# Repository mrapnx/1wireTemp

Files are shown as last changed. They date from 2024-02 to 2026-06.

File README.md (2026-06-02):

1-Wire Busmaster, der die Temperaturen (und Füllstände) angeschlossener 1-Wire Sensoren abfragt und auf einem Display anzeigt sowie per WiFi an einen MQTT Host überträgt.
Durch geringen Stromverbrauch ideal fürs Wohnmobil geeignet.

<kbd>grafik</kbd>
<kbd></kbd>
<kbd></kbd>

# Hardware
## Busmaster mit Display
+ Arduino Nano 33 IoT
+ Display Joy-IT SBC-LCD02 (ILI9163C 1.44" TFT 128x128)
+ Sensor-Button
+ Streifenplatine
+ Gehäuse (Bedieneinheit Gehäuse-Basis.stl / Bedieneinheit Gehäuse-Front.stl)
+ Optional: Temperatursensor DS18B20

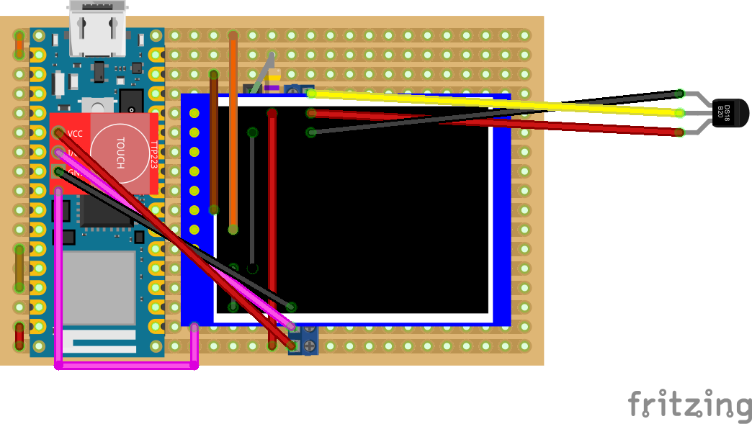
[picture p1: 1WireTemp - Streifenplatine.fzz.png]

  
## Adapter für Tanksonde
+ [Votronic Tanksonde 12-24k](https://www.votronic.de/tankgeber/tankelektrode-14-24-k-und-15-50-k/)
+ Streifenplatine
+ 1-Wire DS2438 Sensor
+ RJ45 Buchse
+ 3 Port-Klemme
+ Gehäuse (DS2438 Sondenadapter Gehäuse-Unterteil.stl)
  
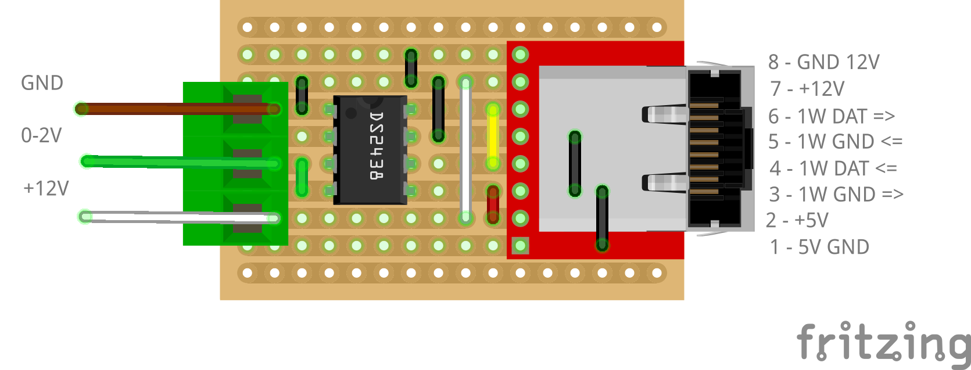
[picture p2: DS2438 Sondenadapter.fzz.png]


## 12V Injektor
+ 2x RJ 45 Buchsen
+ 2 Port-Klemme
+ Downstepper

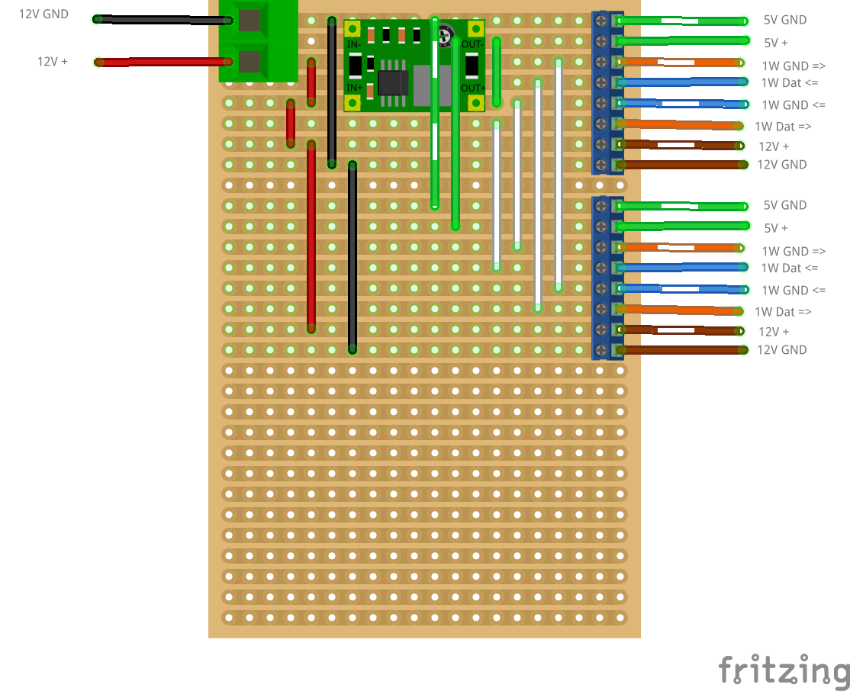
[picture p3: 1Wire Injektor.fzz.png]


# Software
+ VS Code
+ Plaftorm.IO
=> Einfach Repo in Platform.IO öffnen

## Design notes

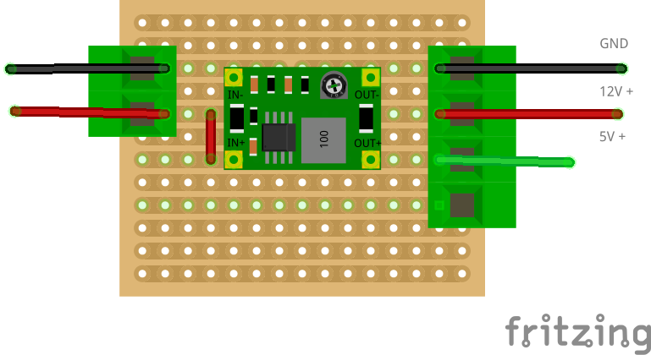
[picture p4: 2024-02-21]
1Wire Netzteil.fzz.png

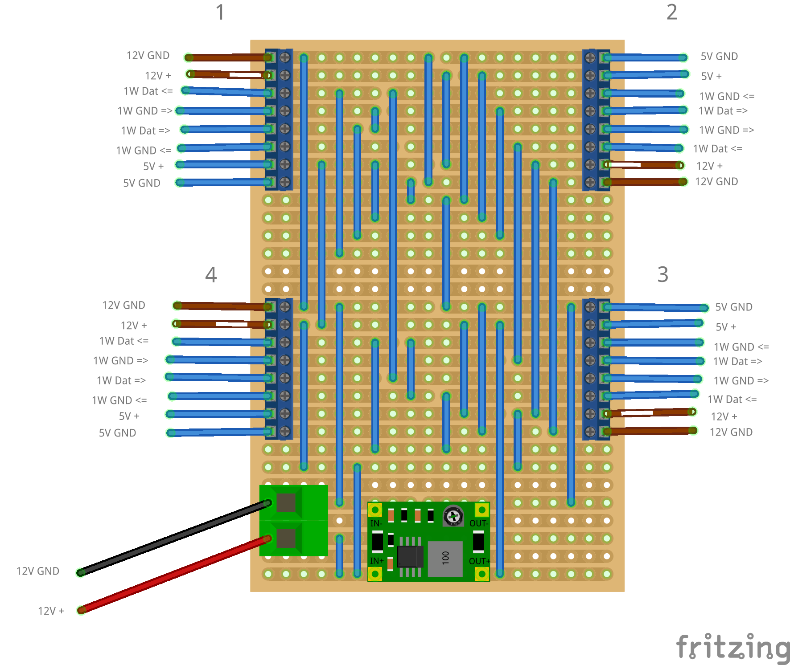
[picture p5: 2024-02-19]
1Wire Verteiler.fzz.png

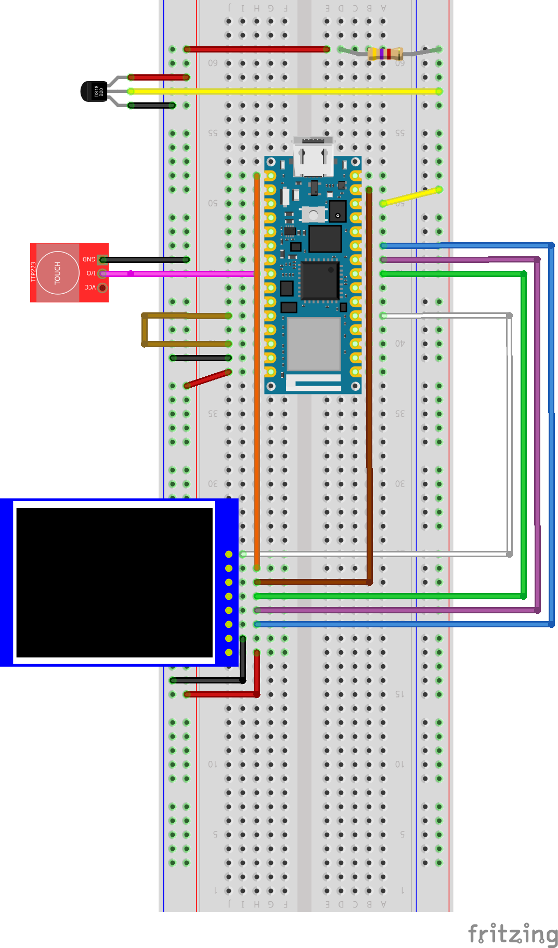
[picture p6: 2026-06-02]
1WireTemp.fzz.png

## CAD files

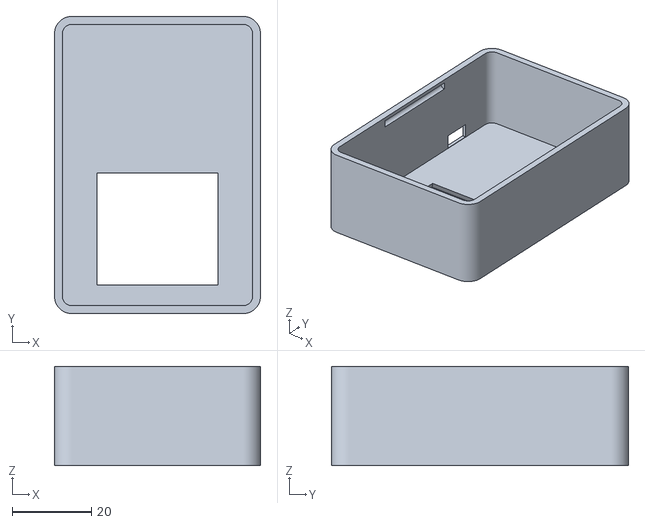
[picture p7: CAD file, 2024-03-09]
Bedieneinheit Gehäuse-Front.stl
52.0 x 75.0 x 25.0

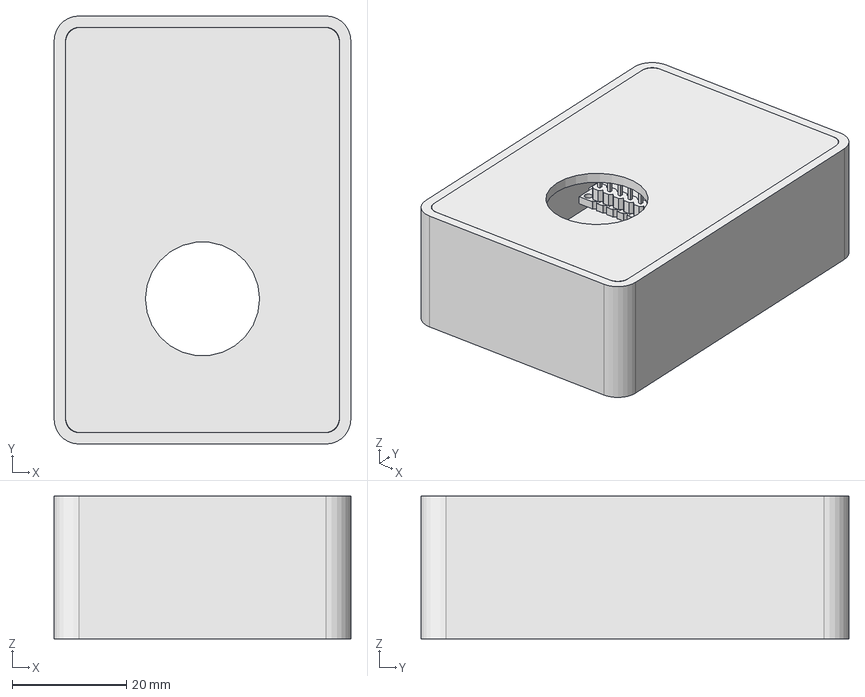
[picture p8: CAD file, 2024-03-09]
Bedieneinheit Gehäuse.FCStd
52.0 x 75.0 x 25.0 mm
Front
Nano_33IoT Body
User Library-arduino_nano_reset core
User Library-arduino_nano_reset shell
atmegaSAMD21
HSMG-C190 LED
HSMG-C190 LED001
ZX62-AB-5PA Micro USB
LSM6DS3 Accelerometer
MPM3610 Step-Down Module
NINA-W102 Body
NINA-W102 Antenna
NINA-W102 Cover
ATECC608A No Lead Crypto Auth
CL21A226MQCLQNC Capacitor
TDK C1005 Capacitor
TDK C1005 Capacitor001
CL21A226MQCLQNC Capacitor001
TDK C1005 Capacitor002
TDK C1005 Capacitor003
PRTR5V0U2X Protection Diode
PMEG6020AELR Diode
C0805C472KDRACTU Capacitor
TDK C1005 Capacitor004
BLM18PG471SN1D Ferrite Bead
TDK C1005 Capacitor005
TDK C1005 Capacitor006
TDK C1005 Capacitor007
GRM188R61E475KE11D Capacitor
RC0402FR-07100KL Resistor
RC0402FR-07100KL Resistor001
RC0402FR-07330RL Resistor
RC0402FR-07330RL Resistor001
RC0402FR-07330RL Resistor002
TDK C1005 Capacitor008
RC0402FR-074K7L Resistor
RC0402FR-074K7L Resistor001
GRM155R61E105KA12D Capacitor
TDK C1005 Capacitor009
RC0402FR-071KL Resistor
RC0402FR-07100KL Resistor002
RC0402FR-07100KL Resistor003
AC0402JR-0724KL Resistor
AC0402JR-0775KL Resistor
dd74adb0230a45f793cde4f0c868591f003
dd74adb0230a45f793cde4f0c868591f004
Basis

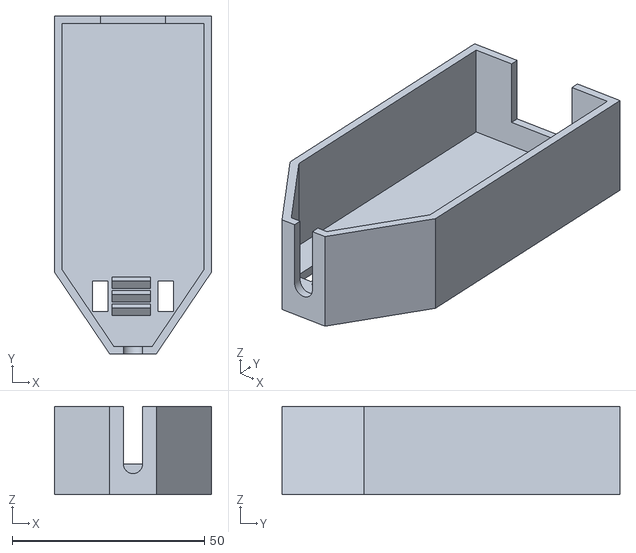
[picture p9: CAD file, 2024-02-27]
DS2438 Sondenadapter Gehäuse-Unterteil.stl
41.0 x 88.0 x 23.0

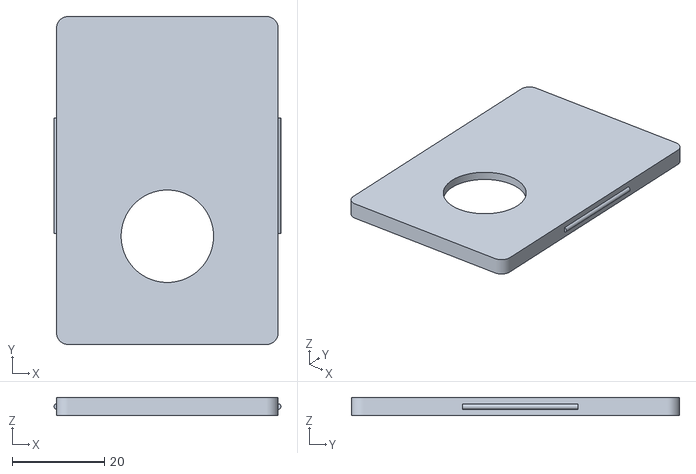
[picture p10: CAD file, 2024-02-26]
Bedieneinheit Gehäuse-Basis.stl
49.1 x 71.0 x 4.00

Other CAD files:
DS2438 Sondenadapter Gehäuse.FCStd

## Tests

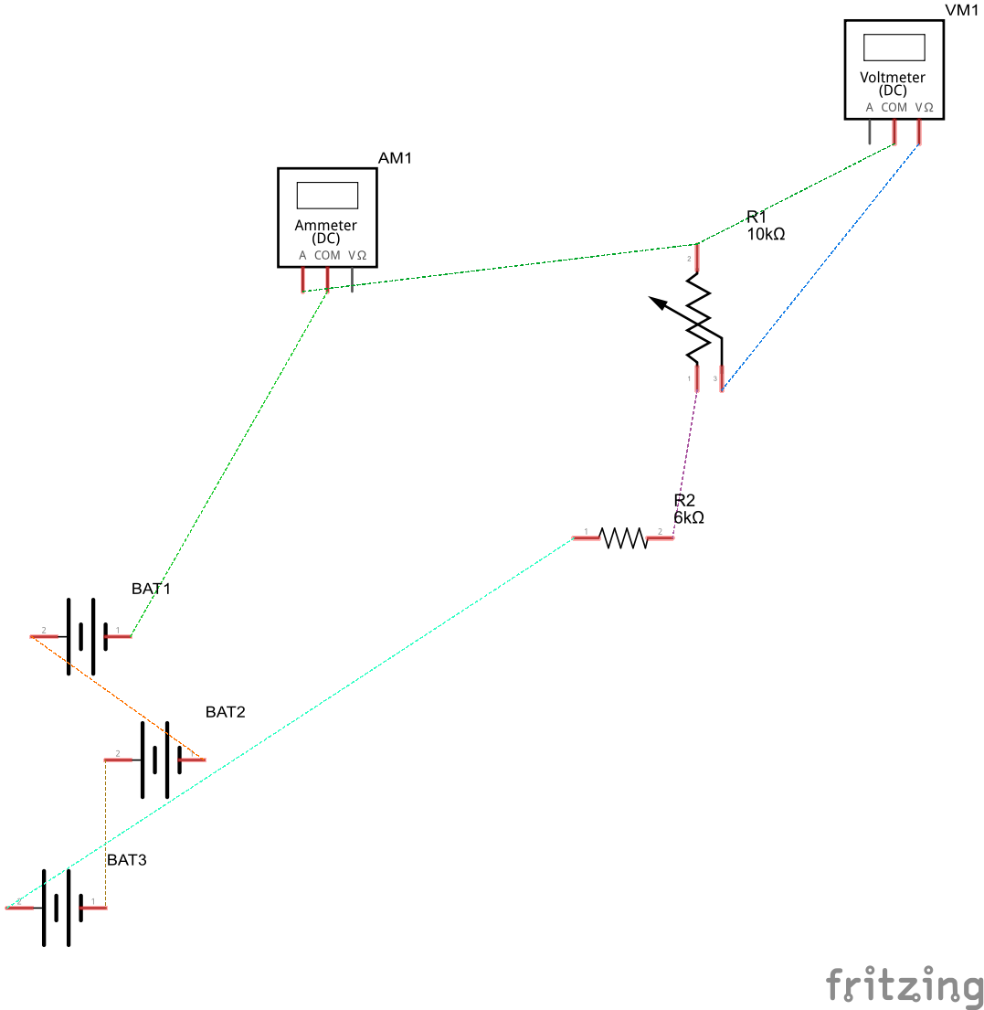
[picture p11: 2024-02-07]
Voltmeter Test_Schaltplan.png

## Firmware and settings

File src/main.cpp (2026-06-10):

/* *************   Wie es geht....

loadConfig()
1. Config wird aus Flash geladen 
   => Config liegt in config.sensorConfig vor

setup1Wire()
2. Alle Sensoren werden per oneWire.search() ermittelt  
   => Sensoren liegen in dallasSensors vor
3. Es wird durch alle Sensoren in dallasSensors iteriert und die Config-Werte ermittelt
4. Zusammen mit den Config-Werten wird nun per addSensor() ein Eintrag in sensors.sensorList erzeugt
   => Nun liegen alle Sensoren in sensors.sensorList vor

loop()
5. Per updateTemperatures() und updateLevels() werden anhand der Sensor-Adressen in sensors.sensorList die aktuellen Werte aus dallasSensors bzw. aus DS2438 ermittelt und in sensors.sensorList geschrieben
6. Per sensorValueToDisplay() wird nun der Wert mit Hilfe der Config im Sensor in einen C-String konvertiert

*/

#include <Arduino.h>
#include <avr/dtostrf.h>
#include <Wire.h>
#include <WiFiNINA.h>
#include <OneWire.h>
#include <DallasTemperature.h>
#include <PubSubClient.h>
#include <SPI.h>
#include <FlashStorage_SAMD.h>
#include <TFT_ILI9163C.h> // Achtung! In der TFT_IL9163C_settings.h muss >> #define __MRA_PCB__ << aktiv sein!. Offenbar ist mein Board nicht von dem Bug betroffen, von dem andere rote Boards betroffen sind. Siehe Readme der TFT_IL9163 Lib.
#include <DS2438.h>
#include "sensors.h"

//#define DRYRUN // Erzeugt Dummy-Sensoren, wenn keine echten angeschlossen sind

// *************** Konfig-Grundeinstellungen
const int sensorConfigCount = 10;  // Gibt fan, wie viele Sensoren konfiguriert und gespeichert werden können

typedef struct {
  char    head           [5] = "MRAb";
  // WLAN
  boolean wifiEnabled        = true;
  char    wifiMode           = 'a'; // a = Access Point / c = Client
  int     wifiTimeout        = 10;
  char    wifiSsid      [21] = "ArduinoAP";
  char    wifiPass      [21] = "ArduinoAP";

  // MQTT-Zugangsdaten
  boolean mqttEnabled        = false;
  char    mqttServer    [21] = "127.0.0.1"; // war: char *mqttServer
  int     mqttPort           = 1883;
  char    mqttName      [21] = "ArduinoClient";
  char    mqttUser      [21] = "ArudinoNano";
  char    mqttPassword  [21] = "DEIN_MQTT_PASSWORT";
  
  // Sensor-Konfiguration
  PersistantSensorConfig sensorConfig[sensorConfigCount];  

  char    foot           [5] = "MRAe";
} Config;

// WLAN-Port
const int wifiPort = 80; // Port, auf den der HTTP-Server lauscht

// Reset Pin
#define RST_PIN  21   // D21

// Button Pin
#define BUTTON_PIN 18 // D18

// Display
#define TFT_LED  2    // Rot    LED   D2 +3.3V
#define TFT_CLK  13   // Orange SCK   D13 / Nicht änderbar
#define TFT_MOSI 11   // Braun  SDA   D11 / Nicht änderbar
#define TFT_DC   5    // Grün   A0    D5
#define TFT_RST  6    // Lila   RES   D6
#define TFT_CS   7    // Blau   CS    D7
                      // Schw.  GND   GND
                      // Rot    VCC   +3.3V   

int       xBegin      = 0;
int       yBegin      = 33;
uint16_t  textColor   = 0xFFFF; // Weiß
uint16_t  backColor   = 0x0000; // Schwarz
boolean   initalClear = false;


// 1-Wire
const int PinOneWireBus = 10; // Pin, an dem der 1-Wire-Bus angeschlossen ist // = D10

// Intervalle
const int wifiCheckInterval   = 10;  // Frequenz in Sekunden, in der die WLAN-Verbindung versucht wird
const int tempCheckInterval   = 5;   // Frequenz in Sekunden, in der die Temperaturen abgefragt werden
const int levelCheckInterval  = 2;   // Frequenz in Sekunden, in der die Füllstände abgefragt werden
const int sendInterval        = 10;  // Frequenz in Sekunden, in der die Temperaturen an MQTT gesendet werden
const int displayInterval     = 10;  // Frequenz in Sekunden, in der die Temperaturen angezeigt werden
const int blinkInterval       = 500; // Frequenz in Millisekunden, in der die orange LED bei Fehlern blinkt


// ***************  Globale Variablen

// Allgemein
unsigned long tempCheckLast   = 0;
unsigned long levelCheckLast  = 0;
unsigned long sendLast        = 0;
unsigned long displayLast     = 0;
unsigned long wifiCheckLast   = 0;
unsigned long blinkLast       = 0;
boolean       blinking        = false;
boolean       buttonState     = false;
boolean       dummySensors    = false;

// 1-Wire
OneWire           oneWire(PinOneWireBus);     // 1-Wire Grundobjekt
DallasTemperature dallasSensors(&oneWire);    // 1-Wire Objekt für Temperatursensoren
Sensors           sensors;                    // Sensorliste

// Webserver
IPAddress   ip; 
WiFiServer  server(wifiPort);
WiFiClient  client; 
int         status = WL_IDLE_STATUS;

// MQTT-Client
WiFiClient   wifiClient;
PubSubClient mqttClient(wifiClient);

// Display
TFT_ILI9163C tft = TFT_ILI9163C(TFT_CS, TFT_DC, TFT_RST);

// Speicher
FlashStorage(configStorage, Config);
Config config;

// *************** Deklaration der Funktionen

// Hilfs-Funktionen
char* fillBlank(const char* input, const u_int length);

// Zustands-Funktionen
boolean sensorsFine();
boolean wifiFine();
boolean checkWiFi();
boolean connectToMQTT();

// Config-Funktionen
boolean loadConfig();
void saveConfig();
void printConfig(Config &pconfig);
void copyConfig(const Config &from, Config &to);

// Sensorlisten-Funktionen
void addSensor(const SensorAddress address, const SensorName name, const SensorType type, const SensorCategory category, const SensorValueFormat format, const SensorValueFormatMin formatMin, const SensorValueFormatMax formatMax, const SensorValuePrecision precision, const SensorValueMin min, const SensorValueMax max, float value); 
void addSensor(Sensor sensor);
void removeSensor(SensorAddress address);
boolean updateSensorValue(const SensorAddress address, const float value);
void clearSensorList();
boolean getSensorCategory(const SensorAddress address, SensorCategory& category);
boolean getSensorConfig(const SensorAddress address, SensorConfig &output);

// Ein- & Ausgabe-Funktionen
void updateTemperatures();
void updateLevels();
void printSensors();
void printSensorAddresses();
void printWiFiStatus();
void displayBackground(); 
void displayValues(); 
void sendTemperaturesToMQTT();
boolean getButtonState();
void reset();

// HTTP-Funktionen
char* getValue(const String& data, const char* key);
String getValuesAsHtml();
char* urlDecode(const char* input);
int hexToDec(char c);
void htmlGetHeader(int refresh);
void htmlGetStatus();
void htmlGetConfig();
void htmlSetConfig();
void httpProcessRequests();

//  Setup-Funktionen
void setup1Wire(); 
void setupDisplay();
void setupMemory();
void setupWifi();
void setup();

// ***************  Funktionen *********************
char* fillBlank(const char* input, const u_int length) {
  static char result[255];
  strcpy(result, input);
  while (strlen(result) < length) {
    strcat(result, " ");
  }
  return result;
  
}


char* urlDecode(const char* input) {
  // Decode URL-encoded data
  String decoded = "";
  char a, b;
  for (size_t i = 0; i < strlen(input); i++) {
    if (input[i] == '%') {
      a = input[++i];
      b = input[++i];
      decoded += char((hexToDec(a) << 4) | hexToDec(b));
    } else {
      if (input[i] == '+') {
        decoded += ' ';
      } else {
        decoded += input[i];
      }
    }
  }

  char* result = new char[decoded.length() + 1];
  strcpy(result, decoded.c_str());
  return result;
}

int hexToDec(char c) {
  return (c >= '0' && c <= '9') ? c - '0' : (c >= 'A' && c <= 'F') ? c - 'A' + 10 : (c >= 'a' && c <= 'f') ? c - 'a' + 10 : 0;
}

char* getValue(const String& data, const char* key) {
  static char result[100]; // Annahme: Der Wert passt in einen 100-Byte-Puffer
  String delimiter = "=";
  char temp[100];
  int keyIndex = data.indexOf(key + delimiter);
  int endIndex;

  Serial.print("getValue(");
  Serial.print(key);
  Serial.println(") begin");
  if (keyIndex == -1) {
    return nullptr;  // Wenn der Schlüssel nicht gefunden wurde, leeres C-String zurückgeben
  }

  keyIndex += strlen(key) + delimiter.length();

  endIndex = data.indexOf('&', keyIndex);
  if (endIndex == -1) {
    endIndex = data.length();
  }

  data.substring(keyIndex, endIndex).toCharArray(result, sizeof(result));

  // Füge den nullterminierenden Zeichen manuell hinzu
  result[sizeof(result) - 1] = '\0';
  Serial.print("  result vor urldecode: ");
  Serial.println(result);
  strcpy(temp, urlDecode(result));
  strcpy(result, temp);
  Serial.print("  result nach urldecode: ");
  Serial.println(result);
  Serial.println("getValue()");
  return result;
}

void copyConfig(const Config &from, Config &to) {
  Serial.println("copyConfig() begin");
  // WiFi
         to.wifiEnabled  = from.wifiEnabled;
         to.wifiMode     = from.wifiMode;
         to.wifiTimeout  = from.wifiTimeout;
  strcpy(to.wifiSsid,      from.wifiSsid);
  strcpy(to.wifiPass,      from.wifiPass);

  // MQTT
         to.mqttEnabled  = from.mqttEnabled;
  strcpy(to.mqttServer,    from.mqttServer);
  strcpy(to.mqttUser,      from.mqttUser);
         to.mqttPort     = from.mqttPort;
  strcpy(to.mqttName,      from.mqttName);
  strcpy(to.mqttPassword,  from.mqttPassword);
  
  // Sensor-Konfig
  for (int i = 0; i < sensorConfigCount; i++) {
    strcpy(to.sensorConfig[i].address,    from.sensorConfig[i].address);  
    strcpy(to.sensorConfig[i].config.name,       from.sensorConfig[i].config.name);  
    strcpy(to.sensorConfig[i].config.format,     from.sensorConfig[i].config.format);  
           to.sensorConfig[i].config.formatMin = from.sensorConfig[i].config.formatMin;
           to.sensorConfig[i].config.formatMax = from.sensorConfig[i].config.formatMax;
           to.sensorConfig[i].config.precision = from.sensorConfig[i].config.precision;
           to.sensorConfig[i].config.min       = from.sensorConfig[i].config.min;
           to.sensorConfig[i].config.max       = from.sensorConfig[i].config.max;
    strcpy(to.sensorConfig[i].config.interpolation, from.sensorConfig[i].config.interpolation);
  }
  Serial.println("copyConfig() end");
};

void printConfig(Config &pconfig) {
  Serial.println("printConfig() begin");

  Serial.print("  wifiEnabled: ");
  Serial.println(int(pconfig.wifiEnabled));

  Serial.print("  ssid: ");
  Serial.println(pconfig.wifiSsid);

  Serial.print("  pass: ");
  Serial.println(pconfig.wifiPass);

  Serial.print("  mode: ");
  Serial.println(pconfig.wifiMode);

  Serial.print("  wifiTimeout: ");
  Serial.println(pconfig.wifiTimeout);

  Serial.print("  mqttEnabled: ");
  Serial.println(int(pconfig.mqttEnabled));

  Serial.print("  mqttServer: ");
  Serial.println(pconfig.mqttServer);

  Serial.print("  mqttPort: ");
  Serial.println(pconfig.mqttPort);

  Serial.print("  mqttName: ");
  Serial.println(pconfig.mqttName);

  Serial.print("  mqttUser: ");
  Serial.println(pconfig.mqttUser);

  Serial.print("  mqttPassword: ");
  Serial.println(pconfig  .mqttPassword);

  for (int i = 0; i < sensorConfigCount; i++) {
    Serial.print("  sensorConfig");  
    Serial.print(i);  
    Serial.print(": Address: ");  
    Serial.print(pconfig.sensorConfig[i].address);  
    Serial.print(" Name: ");  
    Serial.print(pconfig.sensorConfig[i].config.name);  
    Serial.print(" Format: ");  
    Serial.print(pconfig.sensorConfig[i].config.format);  
    Serial.print(" Precision: ");  
    Serial.print(pconfig.sensorConfig[i].config.precision);  
    Serial.print(" Min: ");  
    Serial.print(pconfig.sensorConfig[i].config.min);  
    Serial.print(" Max: ");  
    Serial.print(pconfig.sensorConfig[i].config.max);  
    Serial.print(" Interpolation: ");  
    Serial.println(pconfig.sensorConfig[i].config.interpolation);  
  }

  Serial.println("printConfig() end");
}

void clearSensorList() {
  // Befreie den Speicher von sensorList
  free(sensors.sensorList);

  // Setze die Anzahl der Sensoren auf 0
  sensors.count = 0;

  // Setze den Zeiger auf null, um sicherzustellen, dass er nicht auf ungültigen Speicher zeigt
  sensors.sensorList = nullptr;
}

void saveConfig() {
  Serial.println("saveConfig() begin");

  Serial.println("  Speichere Konfig:");
  printConfig(config);
  EEPROM.put(0, config);

  if (!EEPROM.getCommitASAP()) {
    Serial.println("  CommitASAP nicht gesetzt, führe commit() aus.");
    EEPROM.commit();
  }
  Serial.println("saveConfig() end");
}

boolean loadConfig() {
  Config tempConfig;
  boolean returnValue = false;

  Serial.println("loadConfig() begin");
  Serial.println("  Lade Konfig");
  // Lies den EEPROM bei Adresse 0 aus
  EEPROM.get(0, tempConfig); 
  // Die Struct enthält als erstes immer den C-String "MRA-b" und als letztes immer "MRA-e". Prüfe darauf.
  if (strcmp(tempConfig.head, "MRAb") == 0 && (strcmp(tempConfig.foot, "MRAe") == 0)) {
    Serial.println("  Konfig erfolgreich geladen:");
    copyConfig(tempConfig, config);
    printConfig(config);
    returnValue = true;
  } else {
    Serial.println("  Konfig konnte nicht geladen werden, habe folgendes erhalten:");
    printConfig(tempConfig);
    returnValue = false;
  }
  Serial.println("loadConfig() end");
  return returnValue;
}

void htmlGetHeader(int refresh) {
  // HTTP headers always start with a response code (e.g. HTTP/1.1 200 OK)
  // and a content-type so the client knows what's coming, then a blank line:
  client.println("HTTP/1.1 200 OK");
  client.println("Content-type:text/html");
  client.println();

  // the content of the HTTP response follows the header:
  client.print("<html>");
  client.print("<head>");
  if (refresh > 0) {
    client.print("<meta http-equiv=\"refresh\" content=\"");
    client.print(refresh);
    client.print("; url=http://");
    client.print(ip); 
    client.print("/\"/>");
  }
  client.print("</head>");
}

void htmlGetConfig() {
  htmlGetHeader(0);
  client.print("<html>");
  client.print("  <body>");
  client.print("    <h1>Konfiguration</h1>");
  client.print("    <form method='get' action='/update'>");
  client.print("      <p>WLAN aktiv: <input type='checkbox' name='wifiEnabled' " + String(config.wifiEnabled ? "checked" : "") + "></p>");
  client.print("      <p>SSID: <input type='text' name='wifiSsid' value='" + String(config.wifiSsid) + "'></p>");
  client.print("      <p>Passwort: <input type='text' name='wifiPass' value='" + String(config.wifiPass) + "'></p>");
  client.print("      <p>Modus (a=Access Point, c=Client): <input type='text' name='wifiMode' value='" + String(config.wifiMode) + "'></p>");
  client.print("      <p>WLAN Timeout: <input type='text' name='wifiTimeout' value='" + String(config.wifiTimeout) + "'></p>");

  client.print("      <p>MQTT aktiv: <input type='checkbox' name='mqttEnabled' " + String(config.mqttEnabled ? "checked" : "") + "></p>");
  client.print("      <p>MQTT Server: <input type='text' name='mqttServer' value='" + String(config.mqttServer) + "'></p>");
  client.print("      <p>MQTT Port: <input type='text' name='mqttPort' value='" + String(config.mqttPort) + "'></p>");
  client.print("      <p>MQTT Name: <input type='text' name='mqttName' value='" + String(config.mqttName) + "'></p>");
  client.print("      <p>MQTT Benutzer: <input type='text' name='mqttUser' value='" + String(config.mqttUser) + "'></p>");
  client.print("      <p>MQTT Passwort: <input type='text' name='mqttPassword' value='" + String(config.mqttPassword) + "'></p>");

  client.print("      <p/>");
  client.print("      <table>");
  client.print("        <th></th>");
  client.print("        <th>Adresse</th>");
  client.print("        <th>Name</th>");
  client.print("        <th>Format</th>");
  client.print("        <th>Anzeige Min</th>");
  client.print("        <th>Anzeige Max</th>");
  client.print("        <th>Dezimalstellen</th>");
  client.print("        <th>Sensorwert Min</th>");
  client.print("        <th>Sensorwert Max</th>");
  client.print("        <th>Interpolation Paare</th>");
  for (int i = 0; i < sensorConfigCount; i++) {
    client.print("        <tr>");  
    client.print("          <td>" + String(i) + "</td>");  
    client.print("          <td><input type='text' name='sensorAddress"        + String(i) + "' value='" + String(config.sensorConfig[i].address)   + "'></td>");  
    client.print("          <td><input type='text' name='sensorName"           + String(i) + "' value='" + String(config.sensorConfig[i].config.name)      + "'></td>");  
    client.print("          <td><input type='text' name='sensorValueFormat"    + String(i) + "' value='" + String(config.sensorConfig[i].config.format)    + "'></td>");  
    client.print("          <td><input type='text' name='sensorValueFormatMin" + String(i) + "' value='" + String(config.sensorConfig[i].config.formatMin) + "'></td>");  
    client.print("          <td><input type='text' name='sensorValueFormatMax" + String(i) + "' value='" + String(config.sensorConfig[i].config.formatMax) + "'></td>");  
    client.print("          <td><input type='text' name='sensorValuePrecision" + String(i) + "' value='" + String(config.sensorConfig[i].config.precision) + "'></td>");  
    client.print("          <td><input type='text' name='sensorValueMin"       + String(i) + "' value='" + String(config.sensorConfig[i].config.min)       + "'></td>");  
    client.print("          <td><input type='text' name='sensorValueMax"       + String(i) + "' value='" + String(config.sensorConfig[i].config.max)       + "'></td>");  
    client.print("          <td><input type='text' name='sensorInterpolation"  + String(i) + "' value='" + String(config.sensorConfig[i].config.interpolation) + "' placeholder='e.g. 0=0;50=100;100=200'></td>");  
    client.print("        </tr>");  
  }
  client.print("      </table>");

  client.print("      <input type='submit' value='Speichern'>");
  client.print("    </form>");
  client.print("    <br/>");
  client.print("    <br/>");
  client.print("    <a href=\"/reboot\">Neustart</a>"); 
  client.print("    <br/>");
  client.print("    <br/>");
  client.print("    <br/>");
  client.print("    <a href=\"/\">Zur&uuml;ck</a>");
  client.print("    <br/>");
  client.print("    <br/>");
  client.print("    <a href=\"load\">Konfig laden</a>");
  client.print("  </body>");
  client.print("</html>");
}

void htmlSetConfig() {
  char c;
  char no[2];
  char name[21];
  Serial.println("htmlSetConfig() begin");
  // Lese den HTTP-Body, der die aktualisierten Daten enthält
  String body = "";
  while (client.available()) {
    c = client.read();
    body += c;
  }
  Serial.print("body: ");
  Serial.println(body);

// Wifi
  config.wifiEnabled = body.indexOf("wifiEnabled=on") != -1;
  strcpy(config.wifiSsid, getValue(body, "wifiSsid"));
  strcpy(config.wifiPass, getValue(body, "wifiPass"));
  config.wifiMode = getValue(body, "wifiMode")[0];
  config.wifiTimeout = atoi(getValue(body, "wifiTimeout")); // Umwandlung in Integer

  // MQTT
  config.mqttEnabled = body.indexOf("mqttEnabled=on") != -1;
  strcpy(config.mqttServer, getValue(body, "mqttServer"));
  Serial.print("mqttServer: ");
  Serial.println(config.mqttServer);
  config.mqttPort = atoi(getValue(body, "mqttPort")); // Umwandlung in Integer
  strcpy(config.mqttName, getValue(body, "mqttName"));
  strcpy(config.mqttUser, getValue(body, "mqttUser"));
  strcpy(config.mqttPassword, getValue(body, "mqttPassword"));

  for (int i = 0; i < sensorConfigCount; i++) {
    itoa(i, no, 10);

    strcpy(name, "sensorAddress");
    strcat(name, no);
    strcpy(config.sensorConfig[i].address, getValue(body, name));

    strcpy(name, "sensorName");
    strcat(name, no);
    strcpy(config.sensorConfig[i].config.name, getValue(body, name));

    strcpy(name, "sensorValueFormat");
    strcat(name, no);
    strcpy(config.sensorConfig[i].config.format, getValue(body, name));

    strcpy(name, "sensorValueFormatMin");
    strcat(name, no);
    config.sensorConfig[i].config.formatMin = atof(getValue(body, name)); // Umwandlung nach Float

    strcpy(name, "sensorValueFormatMax");
    strcat(name, no);
    config.sensorConfig[i].config.formatMax = atof(getValue(body, name)); // Umwandlung nach Float

    strcpy(name, "sensorValuePrecision");
    strcat(name, no);
    config.sensorConfig[i].config.precision = atoi(getValue(body, name)); // Umwandlung nach Int

    strcpy(name, "sensorValueMin");
    strcat(name, no);
    config.sensorConfig[i].config.min = atof(getValue(body, name)); // Umwandlung nach Float

    strcpy(name, "sensorValueMax");
    strcat(name, no);
    config.sensorConfig[i].config.max = atof(getValue(body, name)); // Umwandlung nach Float

    strcpy(name, "sensorInterpolation");
    strcat(name, no);
    strcpy(config.sensorConfig[i].config.interpolation, getValue(body, name));
  }

  saveConfig();
  Serial.println("htmlSetConfig() end");
}

void htmlGetStatus() {
  htmlGetHeader(2);
  // client.print("<html><body>");  // ohne  korrektem html und body passt die Schriftgröße irgendwie immer
  client.print("<p style=\"font-size:80px; font-family: monospace\">"); 
  client.print("Sensoren: </br>");
  client.print(getValuesAsHtml());
  client.print("<br/>");
  client.print("<a href=\"/config\">Konfiguration</a><br/>");
  client.print("</p>");
  client.print("</html>");

  // Die HTTP response endet mit einer weiteren Leerzeile:
  client.println();
}
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
void loop() {
  blink();

  getButtonState();

  checkWiFi();

  updateTemperatures();
  updateLevels();

  displayValues(); 

  sendTemperaturesToMQTT();

  httpProcessRequests();

}

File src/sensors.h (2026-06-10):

#include <Arduino.h>
#include <DallasTemperature.h>

typedef char  SensorAddress           [17];
typedef char  SensorName              [21];
typedef char  SensorValueFormat       [11];
typedef int   SensorValuePrecision;
typedef float SensorValueMin;
typedef float SensorValueMax;
typedef float SensorValueFormatMin;
typedef float SensorValueFormatMax;


typedef enum {
	T_DS18B20,
  T_DS18S20,
  T_DS1822,
  T_DS2438,
  T_UNKNOWN
} SensorType;

const char* typeNames[] = {
	"DS18B20",
  "DS18S20",
  "DS1822",
  "DS2438",
  "UNKNOWN"  
};

typedef enum {
	C_DS18B20 = 't',
  C_DS18S20 = 't',
  C_DS1822  = 't',
  C_DS2438  = 'b',
  C_UNKNOWN = 'u'
} SensorCategory;

struct SensorConfig {
  SensorName            name            = "";        // Name zur Anzeige
  SensorValueFormat     format          = "%s";      // Format-String zur Darstellung des Wertes
  SensorValueFormatMin  formatMin       = -1;        // Minimum des Anzeige-Wertes
  SensorValueFormatMax  formatMax       = -1;        // Maximum des Anzeige-Wertes
  SensorValuePrecision  precision       = 0;         // Dezimalstellen des Wertes
  SensorValueMin        min             = -1;        // Minimum des Messwertes 
  SensorValueMax        max             = -1;        // Minimum des Messwertes
  char                  interpolation   [101] = "";  // Interpolationspunkte: "sensorval1=level1;sensorval2=level2"
};

struct PersistantSensorConfig {
  SensorAddress         address         = "";        // Addresse des zu konfigurierenden Sensors
  SensorConfig          config;                      // Anzuwendende Konfig
};

struct Sensor {
  SensorAddress         address         = "";         // Adresse des Sensors userfriendly
  DeviceAddress         deviceAddress;                // Adresse des Sensors als HEX
  SensorCategory        category        = C_UNKNOWN;  // Kategorie, derzeit werden nur t, b und u unterstützt
  SensorType            type            = T_UNKNOWN;  // Typ gemäß Dallas/Maxim
  SensorConfig          config;
  float                 value;
};

struct Sensors {
  Sensor*               sensorList      = nullptr;    // Zeiger auf das Array von SensorData
  int                   count           = 0;          // Aktuelle Anzahl von Sensoren
};


/* 
    Die Logik zur Anzeige ist wie folgt: 

    * Direkt Anzeige
    Der Wert des Sensors wird ermittelt und steht in => value (z.B.  1,5)
    Der Wert kann nun direkt ausgegeben werden (Standard).
    Beispiel
    format ="%s C" / precision = 1  (Implizit: formatMin = -1 / formatMax = -1 / min = -1 / max = -1)
    Bei einem Messwert von 1,5 wird 1,5 C angezeigt.

    * Prozent-Anzeige
    Der Wert kann aber auch in ein Verhältnis gesetzt werden, wenn sich z.B. der Messbereich von 0 bis 3 erstreckt, entspräche 1,5 50%.
    Beispiel:
    Wir messen 0 bis 3 und zeigen das als prozentualen Level an.
    min = 0 / max = 3 / format = "%s %%"   (Implizit: formatMin = -1 / formatMax = -1 / precision = 0)
    Bei value = 1,5 wird dann "50 %" angezeigt (Das doppelte "%%"" führt zur Darstellung von "%").
    
   * Anteilige Anzeige
   Haben wir nun z.B. einen Wassertank, der 120l fasst, können wir auch vom Prozent-Wert auf den anteiligen Wert umrechnen lassen.
   Beispiel:
   Wir messen 0 bis 3 und wollen das als Füllstand von 0 bis 120 l anzeigen.
   min = 0 / max = 3 / formatMin = 0 / fformatMax = 120 / format = "%s l"   (Implizit: precision = 0)
   Bei einem Messwert von 1,5 wird nun "60 l" angezeigt

*/

// *************** Deklaration der Funktionen
byte convertHexCStringToByte(const char* hexString);
String deviceAddressToStr(DeviceAddress addr);
void deviceAddressToStrNew(const DeviceAddress addr, String out);
const char* deviceAddressToChar(DeviceAddress addr); 
bool strToDeviceAddress(const String &str, DeviceAddress &addr);
bool getSensorCategoryByAddress(const SensorAddress manufacturerCode, SensorCategory &sensorCategory);
bool getSensorTypeByAddress(const SensorAddress manufacturerCode, SensorType &sensorType);
void copyDeviceAddress(const DeviceAddress in, DeviceAddress out);
float interpolateFromPairs(const char* interpolationString, const float sensorValue);
void sensorValueToDisplay(const float sensorValue, const SensorValueFormat formatString, const SensorValueFormatMin formatMin, const SensorValueFormatMax formatMax, const SensorValuePrecision precision, const SensorValueMin min, const SensorValueMax max, char displayValue[30]);
void sensorValueToDisplay(const Sensor sensor, char displayValue[30]);

// ***************  Funktionen

// Interpoliert einen Wert basierend auf Paaren im Format "val1=level1;val2=level2;..."
// Beispiel: "0=0;50=120;100=240" mit sensorValue=75 => 180
float interpolateFromPairs(const char* interpolationString, const float sensorValue) {
  Serial.println("interpolateFromPairs() begin");
  Serial.print("  interpolationString: ");
  Serial.println(interpolationString);
  Serial.print("  sensorValue: ");
  Serial.println(sensorValue);

  if (strlen(interpolationString) == 0) {
    Serial.println("  Interpolationstring ist leer, gebe sensorValue zurück");
    Serial.println("interpolateFromPairs() end");
    return sensorValue;
  }

  // Erstelle eine lokale Kopie des Strings zum Parsen
  char tempString[101];
  strncpy(tempString, interpolationString, 100);
  tempString[100] = '\0';

  // Parse alle Paare
  float pairValues[50][2];      // Max. 50 Paare
  int pairCount = 0;
  char* token = strtok(tempString, ";");
  
  while (token != nullptr && pairCount < 50) {
    // Token ist im Format "sensorval=level"
    char* eqPos = strchr(token, '=');
    if (eqPos != nullptr) {
      *eqPos = '\0';  // Trenne die beiden Teile
      float sensorVal = atof(token);
      float level = atof(eqPos + 1);
      pairValues[pairCount][0] = sensorVal;
      pairValues[pairCount][1] = level;
      pairCount++;
      Serial.print("  Pair ");
      Serial.print(pairCount - 1);
      Serial.print(": sensor=");
      Serial.print(sensorVal);
      Serial.print(" level=");
      Serial.println(level);
    }
    token = strtok(nullptr, ";");
  }

  if (pairCount < 2) {
    Serial.println("  Weniger als 2 Paare gefunden, gebe sensorValue zurück");
    Serial.println("interpolateFromPairs() end");
    return sensorValue;
  }

  // Finde die zwei Punkte, zwischen denen sensorValue liegt
  if (sensorValue <= pairValues[0][0]) {
    Serial.print("  sensorValue <= first point, return ");
    Serial.println(pairValues[0][1]);
    Serial.println("interpolateFromPairs() end");
    return pairValues[0][1];
  }
  if (sensorValue >= pairValues[pairCount - 1][0]) {
    Serial.print("  sensorValue >= last point, return ");
    Serial.println(pairValues[pairCount - 1][1]);
    Serial.println("interpolateFromPairs() end");
    return pairValues[pairCount - 1][1];
  }
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

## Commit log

2023-12-12 Wifi und MQTT klappt, 1-Wire noch nicht
2024-01-18 Compiled und läuft
2024-01-18 Funktioniert und gibt Adressen und Temperaturen korrekt aus.
2024-01-18 Temperaturen werden korrekt aktualisiert.
2024-01-18 Globale Sensor-Liste und Typ-Erkennung funktioniert.
2024-01-22 HTML-Konfigseite gebaut und speichern vorbereitet.
2024-01-23 Laden und Speichern der Konfig scheint zu klappen
2024-01-25 Sensor-Konfig eingefügt. Gibt aber noch Probleme beim Laden.
    [main.cpp, sensors.h]
2024-01-26 Laden und Speichern funktioniert jetzt
2024-01-28 DS2438 in Array gezogen, läuft aber auf Fehler bei Temperaturabfrage
2024-02-03 - min und max eingefügt - html eingaben uuencoded - format, min und max müssen noch beim addsensor durchgeschleift werden
2024-02-03 sprintf klappt noch nicht 100%, der Rest ist gut
2024-02-04 - Fritzing-Schaltungen hinzugefügt - Pins geändert, damit sie besser zum Platinen-Layout passen - Display-Beleuchtung schaltbar gemacht - Display gedreht
    [1WireTemp - Streifenplatine.fzz, 1WireTemp.fzz]
2024-02-05 Streifenplatine optimiert
    [1WireTemp - Streifenplatine.fzz]
2024-02-07 - 3D Modelle hinzugefügt - Design-Vorlage für Display hinzugefügt - Voltmeter Schaltung hinzugefügt
    [Bedieneinheit Gehäuse.FCStd, Voltmeter Test.fzz]
2024-02-08 - Bohrung im Gehäuse angepasst - USB Auslass im Gehäuse ergänzt - Pin Belegung auf Streifenplatine angepasst
    [Bedieneinheit Gehäuse.FCStd]
2024-02-08 Touch-Sensor eingefügt
    [1WireTemp - Streifenplatine.fzz, 1WireTemp.fzz]
2024-02-15 Platinenlayout um Terminals ergänzt
    [1WireTemp - Streifenplatine.fzz, 1WireTemp.fzz]
2024-02-16 - DS2438 Adapter für Tanksone ergänzt - Arduino Nano in 1WireTemp korrigiert
    [1WireTemp.fzz, DS2438 Sondenadapter.fzz]
2024-02-17 Sondenadapter korrigiert
    [DS2438 Sondenadapter.fzz]
2024-02-17 Sondenadapter Notiz entfernt
    [DS2438 Sondenadapter.fzz]
2024-02-19 1-Wire Verteiler ergänzt
    [1Wire Verteiler.fzz]
2024-02-20 1-Wire Injektor ergänzt
    [1Wire Injektor.fzz]
2024-02-21 Netzteil-Schaltung ergänzt
    [1Wire Netzteil.fzz]
2024-02-25 DS2438 Adapter auf RJ45 Buchse umgestellt
    [DS2438 Sondenadapter.fzz]
2024-02-25 Sondenadapter ergänzt
    [DS2438 Sondenadapter.fzz]
2024-02-26 Gehäuse STL Export ergänzt
    [Bedieneinheit Gehäuse-Basis.stl, Bedieneinheit Gehäuse-Front.stl]
2024-02-26 Sondenadapter Gehäuse begonnen
    [DS2438 Sondenadapter Gehäuse-Unterteil.stl, DS2438 Sondenadapter Gehäuse.FCStd]
2024-02-27 DS2438 Gehäuse RJ45 Auslassung vergrößert und Zugentlastung ergänzt
    [DS2438 Sondenadapter Gehäuse-Unterteil.stl, DS2438 Sondenadapter Gehäuse.FCStd]
2024-03-02 Anzeige mit FormatString korrigiert
    [main.cpp, sensors.h]
2024-03-07 Oberschale verkürzt, Nut und Feder müssen aber noch angepasst werden
    [Bedieneinheit Gehäuse.FCStd]
2024-03-07 Kürzung fertig gestellt
    [Bedieneinheit Gehäuse-Front.stl, Bedieneinheit Gehäuse.FCStd]
2024-03-09 Gehäuse korrigiert
    [Bedieneinheit Gehäuse-Front.stl, Bedieneinheit Gehäuse.FCStd]
2024-03-15 Fixes aus branch imu übernommen
    [main.cpp]
2024-03-16 Refactoring: Sensor-Structs
2024-03-21 Nochn fix in getSensorConfig()
    [main.cpp]
2024-03-25 - Korrektur am Fritzing Plan - Errorcode-Ausgabe für setupDispaly()
    [1WireTemp.fzz]
2024-04-08 Leerzeichen hinter dem Sensorwert ergänzt, damit verwaiste Zeichen überschrieben werden
2024-04-15 12V Eingang als Testprojekt hinzugefügt 1Wire Unterverteiler angefangen
    [1Wire 12V Eingang.fzz, 1Wire Unterverteiler.fzz]
2024-10-14 Bugfix bei Verwendung von DRYRUN
    [main.cpp]
2026-06-02 USB-C Unterverteilung ergänzt (In Bearbeitung)
    [1Wire Unterverteiler RJ45.fzz, 1Wire Unterverteiler USB-C.fzz]
2026-06-02 Schaltplan Entwurf abgeschlossen
    [1Wire Unterverteiler USB-C.fzz]
2026-06-02 Belegung korrigiert, Widerstand korrigiert, Sensoren ergänzt
    [1WireTemp - Streifenplatine.fzz, 1WireTemp.fzz]
2026-06-02 Sensor Typen ergänzt
    Cherry-Picking die Sensor-Typ-Ergänzung
2026-06-02 Bug aus dem Cherry-Picking gefixed
    [main.cpp]
2026-06-02 Fehlerbehandlung für Temp-sensoren eingebaut und DallasTemperature hochgezogen
